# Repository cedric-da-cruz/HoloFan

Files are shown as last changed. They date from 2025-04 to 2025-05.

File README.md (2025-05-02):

# HoloFan
Conception of an holographic fan

- Datasheet : Contain the datasheets of the different components (if available)
- Deliverable : Contain document such as prestentation (pptx) ,report (pdf), and the Capella
- Electrical circuit : Contain the global powering circuit & the .json files (EasyEDA) of the PCB
- Manefacture : Contain the CREO files of the wooden box and PLA PCB case
- Software : Contain the different programs created and used
- Weekly Reports : Contain the weekly report to our tutor

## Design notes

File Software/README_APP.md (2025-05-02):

- In the file Fan_app.zip, you will find the files for the application of the fan. This is the software used to get an image send it to the fan.
- In the file Test_fan_app.zip, you will find the function used to test the integrity of the data by creating an image from the data in the byte array.

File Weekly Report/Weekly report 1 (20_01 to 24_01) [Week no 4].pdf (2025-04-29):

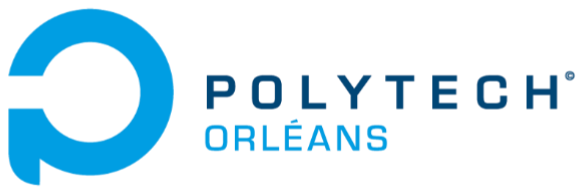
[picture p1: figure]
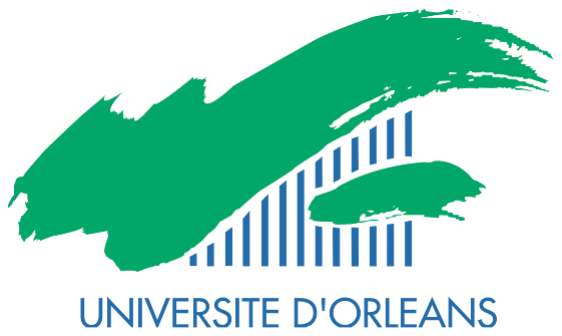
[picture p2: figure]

# Weekly Report

## Week 4 : 20/01/2025 – 24/01/2025

Eloïse MESTRE

Project Tutor

Mustafa TOPBAS

4A GPSE

Axel LEROY

4A GPSE

Cédric DA CRUZ

4A GPSE

Abigaïl BROCHARD

4A GPSE

Mustafa TOPBAS - Axel LEROY - Cédric DA CRUZ - Abigaïl BROCHARD - 4A GPSE
Eloïse MESTRE – Project Tutor | 1

1-Mustafa

Number of hours spent on the project this week: 10 hours

Activity:

Tuesday [21/01/2025]: I participated in amperage measurements on the

prototype. We unsoldered so we could measure the current in series with

a multimeter. With Cédric and Axel, we concluded that a minimum of 4.7V

was needed for around 300mA.

Wednesday [22/01/2025]: Given that the others were either absent or

presenting the specialty to younger students. I took the initiative to start

the electrical diagram including the LEDs, communication protocol and

microcontroller. After presenting this to the group and adjusting it

together, we distributed the tasks for the second semester. After that, I

wanted to start making a more serious electrical diagram on professional

software. The software we used in class did not include "footprint" of the

LEDs. This is important for the rooting process that we will encounter in the

future. So, I installed professional software. I started a diagram on it.

For the distribution of tasks, we decided that I was going to continue the

electrical diagram, make the PCB and work on the amperage and power

supply. Cédric will be with me for these games during this semester.

Thursday [23/01/2025]: With Axel and Ms. Debrus, we started the business

plan for our project. To do this, we filled out a BMC (Business Model Canva).

This table will be useful because it gives an overall vision of the business

plan, which we can return to in detail.

Friday [24/01/2025]: We reviewed what was wrong in our CDD (Capability

development document) with you, our tutor.

2-Axel

Number of hours spent on the project this week: 8 hours

Activities: I had 5 activities this week.

First activity: 1h

My first activity was to measure the inductive output current and

voltage needed to power the Arduino and the HC-06 (Bluetooth module)

with Mustafa and Cedric. We concluded that we needed a minimum of 4.7V

with a current of 300mA.

Second activity: 2h

My second activity was to continue the coding of the application. I

mostly worked on the way to get pixel data from an image. So, I worked in the same framework as the prototype’s app in C# (because I can reuse C#

functions in the .NET MAUI framework). I found the function lockbit that

returns an array of RGB data from a pixel of a Bitmap type image.

Third activity: 2h

My third activity was to help Cedric to make the motor work. We tried

several codes and tried to use several Arduino pins to control the motor,

but we didn’t manage to start the motor at all. We suspect the issue to be

with the ESC (Electonic Speed Controler) that is between the Arduino and

the motor, which is supposed power the motor. As there is very little data

about how to use this ESC, it is probable that we didn’t use it correctly.

Fourth activity: 1h

My fourth activity was to start the business plan of the project with

Mustafa and Ms. Debrus. We worked on how to make an appropriate

Business Model Canva for our project. For example, we determined who

would use our product, what services we could offer, or even how much

we could sell one of our products for.

Fifth activity: 2h

My fifth activity was to review the CDD (Capability Development

Document) with our tutor (you), Mustafa and Cedric.

3-Cédric
Number of hours spent on the project this week: 6 hours (+2 on Friday)

Activity:

Firstly, Axel, Mustafa, and me, tested the prototype to check the working

current and tension input. We concluded that we needed a minimum of

4.7V with a current of 300mA on the input coil for the prototype to be

powered properly. More extensive test will be needed on the final version

which will incorporate the chosen LEDs.

Secondly, I started working on the brushless motor and the ESC

(electronic speed controller). I encountered great problems as I couldn’t

make them work. The problem seems to originate from the ESC, as it

seems to need a specific starting protocol which wasn’t indicated on the

specifications of the product.

4-Abigail

Number of hours spent on the project this week:

Activity:

I was absent Tuesday and Wednesday morning, so I was only able to be

there Wednesday afternoon. I ordered the LEDs from Mr. LADROUZ. After

we have divided the tasks, I will take care of the design of the base to

print it with a 3D printer.

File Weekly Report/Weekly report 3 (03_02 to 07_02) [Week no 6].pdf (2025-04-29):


# Weekly Report

## Week 6: 03/02/2025 – 07/02/2025

Eloïse MESTRE

Project Tutor

Mustafa TOPBAS

4A GPSE

Axel LEROY

4A GPSE

Cédric DA CRUZ

4A GPSE

Abigaïl BROCHARD

4A GPSE

Mustafa TOPBAS - Axel LEROY - Cédric DA CRUZ - Abigaïl BROCHARD - 4A GPSE
Eloïse MESTRE – Project Tutor | 1

1-Mustafa

Number of hours spent on the project this week: 6.5 hours

Activity:

Monday [03/02/2025]: 3.5 hours

This morning, I used the diagram on paper that I had made for the system

power supply. I determined that it was necessary to receive 5V, 4A therefore

20W in total to power the blade. The induction component I had could only send

5V and 1A so it's not good enough. I tried to unsolder its rectifier part to measure

and make a rectifier myself later, but the transmitter burned, I don't know why.

I either must find a new component or take this one back to repair it by modify-

ing.

Wednesday [05/02/2025]: 3 hours

I started by looking for components to replace our burnt out induction

coils. I found a similar component that sends 100W, 24 to 32V and up to 4A.

Which corresponds to what I need to power the blade. I also looked for a

converter to be able to use the sector to power the system. I found a 220V to

24V converter. After that, I brainstormed with Axel to help with the code.

2-Axel

Number of hours spent on the project this week: 6 hours

Activities: I had 3 activities this week.

First activity: 2h30

My first activity was to keep working on the way to get RGB data from

the image. This time, using a “for” loop and adapting a bit the previous

program to get the lengths right, I managed to get the data from the whole

image, line by line. To lose as little time as possible, I didn’t try to display it

as I know the data stored in the byte array is right.

Second activity: 1h

My second activity was to help Mustafa with the measure of the

maximum power transmittable by the inductive coils. In doing so, the

inverter heated and burnt out. We don’t really know why as we used it with

a voltage of 12V and a current of 1A, which we had already used before and

worked well. These values being in the range written in the datasheet of

the component, we think one of the individual components had a fault.

Third activity: 2h30

My third activity was to work on the cropper and zoom part of the

app. Still in C# Winform, I managed to zoom in and out of an image with a

trackbar. Currently I am trying to work on a way to adapt the amount of

zoom possible to the original size of the image.

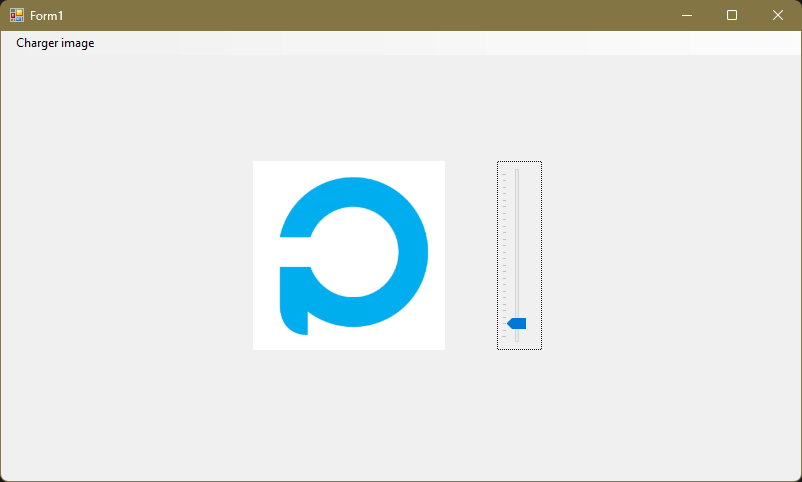
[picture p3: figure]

Screenshot of the app with the trackbar

3-Cédric
Number of hours spent on the project this week: 5 hours

Activity:

I mainly did test on the motor to check its power consumption

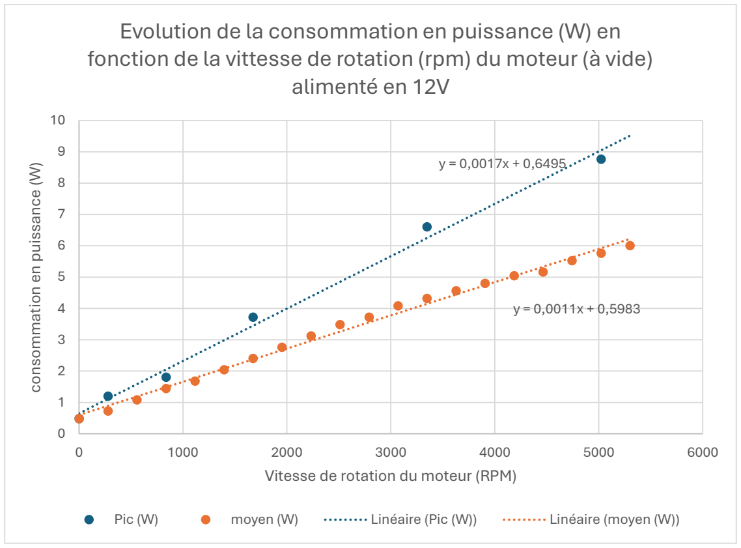
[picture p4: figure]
consommation en puissance (W); Vitesse de rotation du moteur (RPM); alimenté en 12V; Pic (W); moyen (W); Linéaire (Pic (W)); Linéaire (moyen (W))

For speed range (900-1300 RPM) we would have a maximum

consumption of 4W (12V 330mA).

I also tried repairing the induction coils but to no avails

### Evolution de la consommation en puissance (W) en fonction de la vittesse de rotation (rpm) du moteur (à vide)

4-Abigail

Number of hours spent on the project this week: 1.5h

Activity:

I was ill all week (and was off work for three days) and the doctor ordered

me not to work in order to get better. As soon as I felt better, I wanted to get

back to the project, because I know I'm behind schedule. I'm going to have a lot

of work to do next week, as my colleagues are making better progress.

Back to the facts:

I did an initial CAD test on Onshape

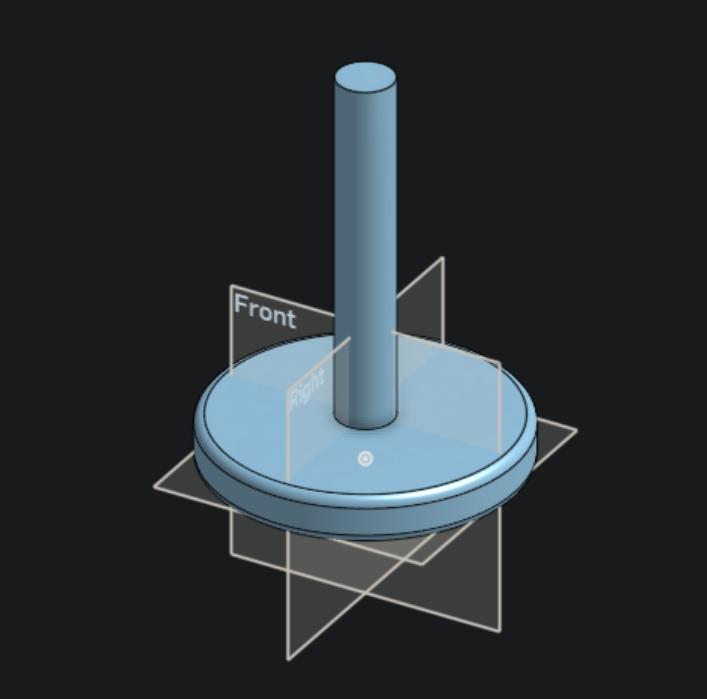
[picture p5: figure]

For the moment, there aren't any real measurements, but I wanted to fa-

miliarize myself with the software so that I could see for myself what we could

do with the boys and then send them into production.

I then started drawing the electrical diagram for my LEDs on EASYEDA to

check the connections to the datasheets and microcontrollers. It's not at all well

optimized yet, and on Monday I'll be drawing it on a sheet of paper to see how

to place everything properly.

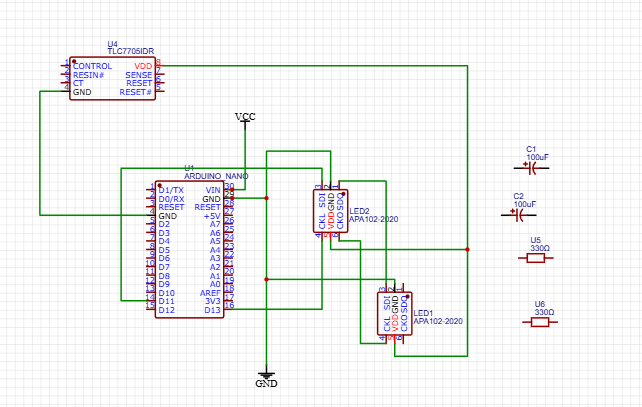
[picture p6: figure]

I know I'll have to add pull-up resistors and stabilizing capacitors to com-

pensate for voltage drops. But for the moment I've really technically linked the

various inputs and outputs and two LEDs together according to the SPI commu-

nication protocol:

DATA (DI) → MOSI (D11 on Arduino)

CLOCK (CI) → SCK (D13 on Arduino)

DATA OUT (DO) and CLOCK OUT (CO) go to next LED

VCC and GND in parallel on all LEDs

5V Power Supply → VCC of LEDs

GND Power Supply → GND of LEDs and Arduino

The connections will be in series for communication, and in shunt for

power supply.

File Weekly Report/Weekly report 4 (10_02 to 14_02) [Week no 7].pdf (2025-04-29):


# Weekly Report

## Week 7: 10/02/2025 – 14/02/2025

Eloïse MESTRE

Project Tutor

Mustafa TOPBAS

4A GPSE

Axel LEROY

4A GPSE

Cédric DA CRUZ

4A GPSE

Abigaïl BROCHARD

4A GPSE

Mustafa TOPBAS - Axel LEROY - Cédric DA CRUZ - Abigaïl BROCHARD - 4A GPSE
Eloïse MESTRE – Project Tutor | 1

1-Mustafa

Number of hours spent on the project this week: 6.5 hours

Activity:

Monday [10/02/2025]: 3 hours

Today, I started by learning about buck converters after a discussion with

Loann. After that, I looked at the LED footprint that Aby had found, we deter-

mined that it was not good. I then took a clean look at my power supply diagram

in Word. I now have to find a good buck converter and other components.

Thursday [13/02/2025]: 3.5 hours

Today I found the buck converter I needed as well as the 24V-12V con-

verter. After a discussion with Mr. Ladrouz, who explained to us that the orders

were going to be complicated and taking into account the fact that if we wanted

to manufacture these components ourselves, we would run out of time, we de-

cided to place the orders ourselves by dividing the sum by 4. The orders were

placed on Ali Express for budget reasons. These are the 4 components that I

chose. After that, I took the electrical diagram that Abigail made for the blade, I

checked it and I added the power supply part that I take care of. I plan to screw

the buck converter onto the PCB, I chose a component that provides holes for

this.

2-Axel

Number of hours spent on the project this week: 6 hours

Activities: I had 4 activities this week.

First activity: 2h

My first activity was to adapt the amount of zoom possible (and initial

zoom) according to the original size of the image. To do so, I used the zoom

function I had already made right after uploading the image on the

application. I also adapted the minimum zoom so that the image will fit to

the size even if it is originally smaller. Finally, I created factors that depend

on the size of the image to adapt the maximum zoom.

Second activity: 30 min

My second activity was to discuss with Cedric about the algorithm we

could use to transform the array of byte from x and y coordinates to r and

θ one. Indeed, to use the array in the Arduino, it would be easier to get the

RGB data using r and θ.

Third activity: 2h

My third activity was to try to move the image inside the picturebox

once it was zoomed in. I tried several ways, but I didn’t manage to make it

work. I intend to go back to work on this part, but as it is less important than some other parts of the app, I didn’t want to spend too much time

trying to make it work.

Fourth activity: 1h30

My fourth activity was to put all the individual working parts of the

app in one final app for the prototype. I will update frequently this app with

the new parts I manage to make work.

3-Cédric
Number of hours spent on the project this week: 6.5 hours

Activity:

I made some research for Axel on an algorithm that would transform an

image from cartesian coordinate to polar coordinate. I found some pre

existing code that could help and transfered it to Axel. I also worked with

Mustafa on plotting the electrical circuit.

4-Abigail

Number of hours spent on the project this week: 4h

Activity: Led diagram 3h

This week I reviewed the entire electrical diagram of the LED

I changed the footprint to exactly match the shape on the datasheet and

changed the connection placements as well.

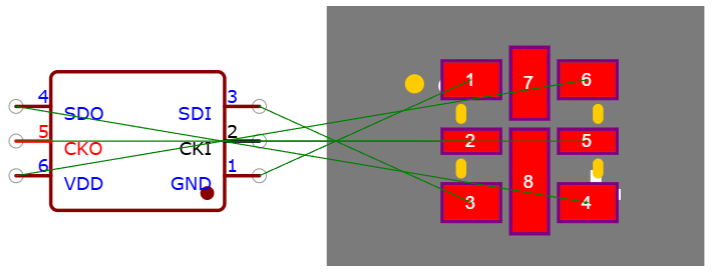
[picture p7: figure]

Then afterwards I had to try to place everything exactly as in the future fan,

remake the correct connections and do that 149 times.

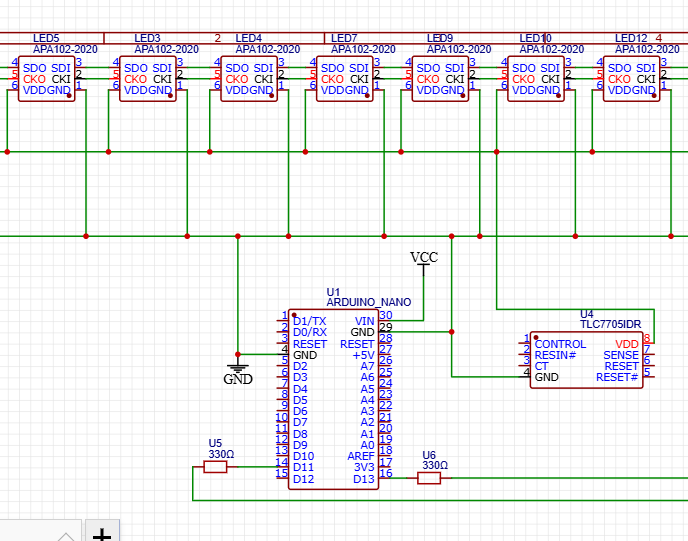
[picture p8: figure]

Activity: Business plan : 1h30

I took all the notes on the business plan that we had in relation to the

business canvas made earlier in the month to put everything in order. The

objective was to be able to prepare for the back-to-school oral exam.

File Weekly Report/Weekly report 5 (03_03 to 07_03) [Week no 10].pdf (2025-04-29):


# Weekly Report

## Week 10: 03/03/2025 – 07/03/2025

Eloïse MESTRE

Project Tutor

Mustafa TOPBAS

4A GPSE

Axel LEROY

4A GPSE

Cédric DA CRUZ

4A GPSE

Abigaïl BROCHARD

4A GPSE

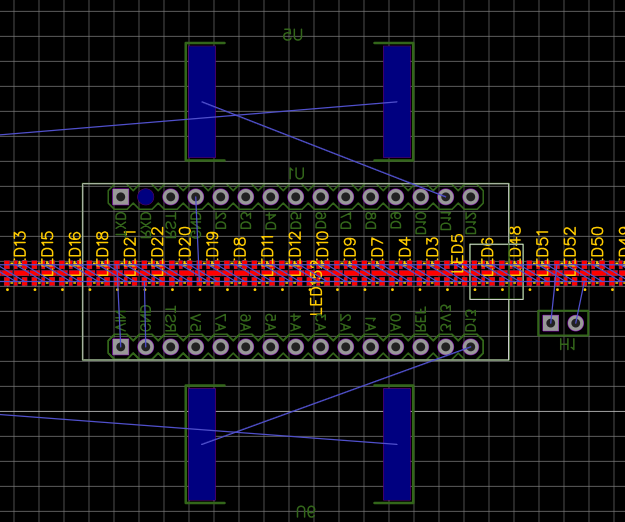
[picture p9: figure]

Mustafa TOPBAS - Axel LEROY - Cédric DA CRUZ - Abigaïl BROCHARD - 4A GPSE
Eloïse MESTRE – Project Tutor | 1

1-Mustafa

Number of hours spent on the project this week: 3.5 hours

Activity:

Monday [03/03/2025]: 3.5 hours

Today I started the PCB. I aligned the 150 LEDs which took me a lot of time.

I now must make the connections considering the width of the tracks to support

4A.

2-Axel

Number of hours spent on the project this week: 3.5 hours

Activities: I had 1 activity this week.

First activity: 3h30

My activity was to try to make work the translation function. As it is

not possible (or I haven’t found the way yet) to make it work with the

picture box, I tried to completely change the way I display the image. I tried

displaying it in several ways: inside a button, inside a rectangle entity, …

But I haven’t managed to make the translation work with the previous

functions.

3-Cédric
Number of hours spent on the project this week: 3.5 hours

Activity:

I did test on the replacement component we received. Since they aren’t

finished i’ll finish them and insert the result and graph on the next weekly

report

4-Abigail

Number of hours spent on the project this week: 3

Activity: Led and angular 3h

For this week, I asked Kamel for an angular sensor and some LEDs that could

be the closest to the ones I wanted for the project, so I could start coding

on them until I could buy the right materials.

The references for the LEDs are SK6812.

SK6812s are easier to connect and use fewer wires, but their

synchronization is not as good, which can be a problem if your system is

running at high speed.

- APA102s are much better for smooth, accurate display, thanks to

their SPI protocol and high refresh rate.

I'll have to take that into account for the code so I don't have too much

work to change the led afterwards.

For the angular sensor, the reference is the DR5013.

The DRV5013 is not a precise angular position sensor, it only detects

whether a magnet is present or not. It won't give you a precise angle.

- The AS5600 is designed for angular measurement and is much

more precise.

It's going to be more complicated to code because it's really not as good

as my basic sensor and Kamel doesn't have anything better, so I'll have to

find a solution quickly.

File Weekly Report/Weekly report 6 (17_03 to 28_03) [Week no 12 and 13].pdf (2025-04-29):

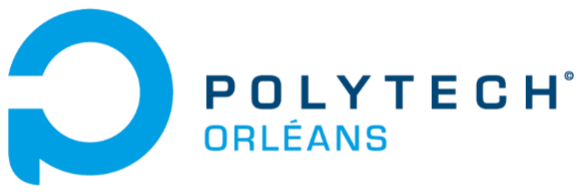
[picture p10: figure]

# Weekly Report

# Week 12-13: 17/03/2025 – 28/03/2025

## Eloïse MESTRE

## Project Tutor

## Mustafa TOPBAS

## 4A GPSE

## Axel LEROY

## 4A GPSE

## Cédric DA CRUZ

## 4A GPSE

## Abigaïl BROCHARD

## 4A GPSE

Mustafa TOPBAS - Axel LEROY - Cédric DA CRUZ - Abigaïl BROCHARD - 4A GPSE
Eloïse MESTRE – Project Tutor | 1

### 1-Mustafa

### Number of hours spent on the project this week: 2.5 + 4.25 + 4 + 2 =

### 12,75hours

### Activity:

Until March 26th at 12:30, I worked on the PCB that I had almost finished. All that remained

was to add the copper layers. But we received our LEDs which were deemed too small to be

soldered, which makes all my work on the PCB useless. So I will have to start again from the

electrical diagram. Also, the almost finished diagram had encountered problems that had

canceled all my connections, so I had to start again from the rooting. It was rather difficult to

believe that it was necessary to start all over again.

On the afternoon of March 26, I looked for the footprint, I found a similar one but I couldn't

import it. Mr. Ladrouz improvised a course for me on how to make a footprint but I still didn't

have all the keys to succeed.

I finally found a footprint that fit what I needed. I sent it to Abigail, who lined up the 60 LEDs

for me. We reduced the number of LEDs because the new ones are wider and we have PCB

size limitations.

On Friday, March 28, I took Abigail's aligned LEDs to make the electrical diagram of the project

once again. This time, I added the Hall effect sensor, the datasheet for which I had to read. I

also added the Bluetooth module. I did some research on the size of the tracks, for that I took

a book that we had to read as part of our courses. I ended up adding decoupling capacitors.

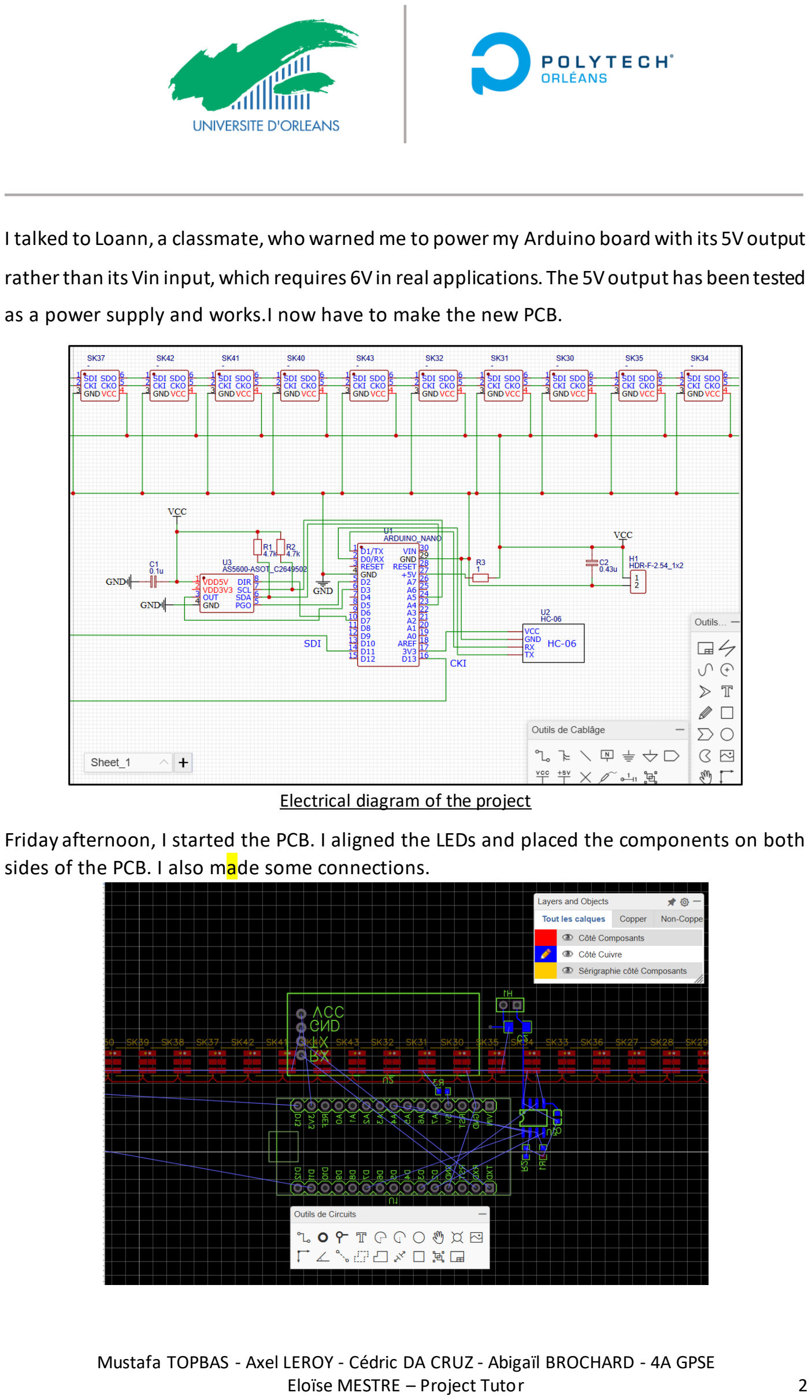
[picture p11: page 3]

I talked to Loann, a classmate, who warned me to power my Arduino board with its 5V output

rather than its Vin input, which requires 6V in real applications. The 5V output has been tested

as a power supply and works.I now have to make the new PCB.

Electrical diagram of the project

Friday afternoon, I started the PCB. I aligned the LEDs and placed the components on both sides of the PCB. I also made some connections.

### 2-Axel

### Number of hours spent on the project this week: 13h45

### Activity:

Last week, I used 3h45 to work on a way to move the image within the picturebox. I

had the idea to use a Graphicstype object which “tells” how manage the display of anything

graphic (images, drawings, etc). On this object I used the function FromImage(Image) to

specify which image the Graphics object applies to. Then, I used the function

DrawImage(Image, Point), which draws the image to the location specified by the point.

However,this function still isn’t enough to move the image within the picturebox because we

need to set the picturebox.Image (parameter to access the image of the picturebox) to this

new image. To do so I created a Bitmap object that copies the “new image” and then I set the

picturebox.Image to the Bitmap object. Beforehand, I also set the interpolation mode of the

Graphics object.

This week, I tried to crop the image once the user is satisfied with its size. To do so, I

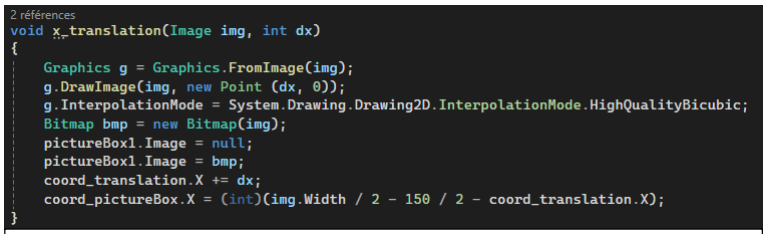
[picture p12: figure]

found | the | function

This function creates a copy of a section of a Bitmap. I could the same PixelFormat as the

original image, however I had to know what section I wanted to copy. To create a rectangle,

X_translation function, exists also for Y_translation we need a point to set the coordinates and a size. The size being set by the numbers of LEDs

on the fan. The biggest issue was the coordinates. Most of the 10 hours I spent on this part of

the project were related to these coordinates. It was easy to set a coordinates variable that

changes with the X and Y_translation functions, yet with the zoom function. So, I had to create

one point for X and Y_translation and one that always knows where the picturebox is within

the image (when the image is zoomed in, it theoretically is bigger than the picturebox, even if

we can only see the part inside the picturebox).

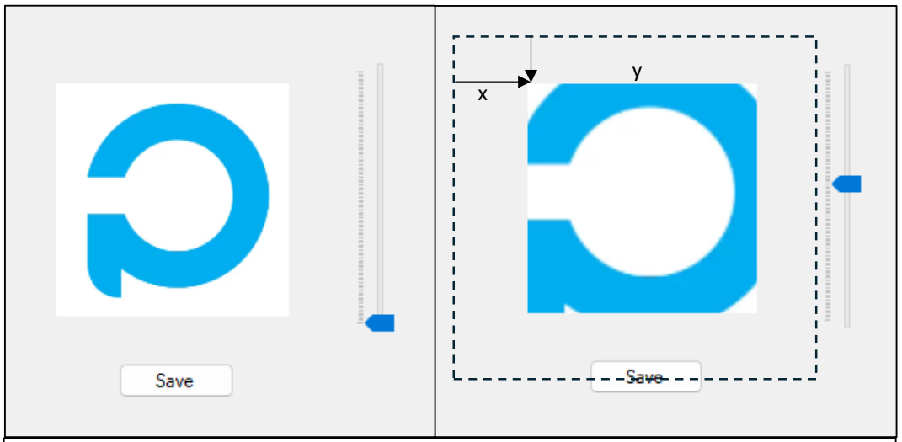
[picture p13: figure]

I also used these coordinates to manage the border limits of the image (not being able

to move outside of the image, nor to zoom out of the image when on one side).

Coordinates changing when zooming in/out

### 3-Cédric Number of hours spent on the project this week: 10

### Activity:

Last week I finished the different test on the component we received

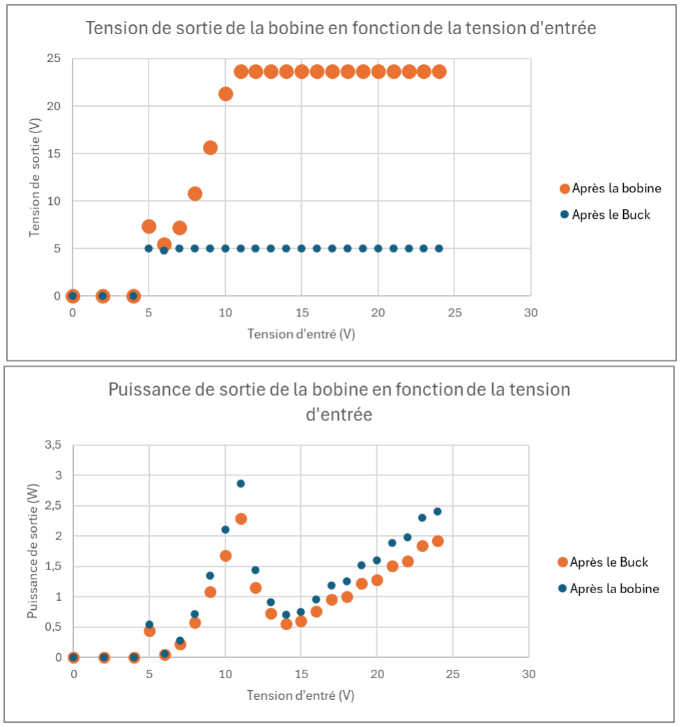
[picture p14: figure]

This week with Abigaïl we had a meeting with Ms NOVELLO, we discussed over the base on

which the motor will be fixed and who will contain the different electronic components. We

decided to go with 8mm thick composite wood and 10mm thick transparent plexiglass for

the materials. We have a meeting Friday next week to start the cutting and building process

### 4-Abigaïl

### Number of hours spent on the project this week: 2,5 (Wednesday March 26th

morning) + 2,5 (Wednesday March 26th afternoon) + 2 (Thursday March 27th evening) + 3,5

(Friday March 278h morning) -> 10,5

### Activity :

When we received our LEDs, we realized that they were really too small to solder ourselves.

It might have worked if we'd been able to subcontract, but it's not possible. So, I went to see

Kamel to try and find a solution, and we found a new reference of LEDs that would work.

We had to get away from the theory I had studied, which was that we needed small LEDs to

get the maximum number and exceptional synchronization.

The LED reference is SK9822. These are LEDs with the same communication protocol as the

old ones (APA-102), but their synchronization is slower than the others. They also have a more

unstable frequency starting at 4 MHz(compared with 20 MHzfor the others). These are details

that would count for a very professional rendering for a company, but we'll have to make do.

The LEDs are therefore larger. They're 5 mm in size, which means we'll have to use fewer of

them, and therefore get poorer quality. If we keep the 30 cm length for our pall, that gives us

60 LEDs.

So, I drew up the LED diagram with the new reference as quickly as possible, so that Mustafa

could start on the PCB on Friday morning. Fortunately, the SK9822s and APA-102s aren't that

far apart in terms of wiring, as this enabled me to go faster than if I'd had to start from scratch.

On Friday morning, Cédric and I went to the FABLAB to talk with Clarisse Novello about how

we're going to create the box that will hold our connectors and the Plexiglas protection. The

aim is to be able to fit the plexiglass and the wooden box together. Cédric can explain it better

than I can. Personally, I'll be modeling the plexiglass part in CREO with the following plans:

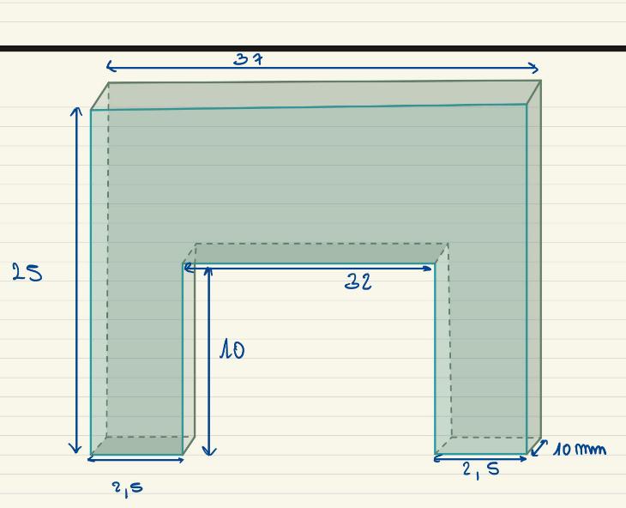
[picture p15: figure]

The drawing above is a side-by-side representation of the Plexiglasshape with measurements

(in cm overall and in mm where specified).

and below is the top view with measurements

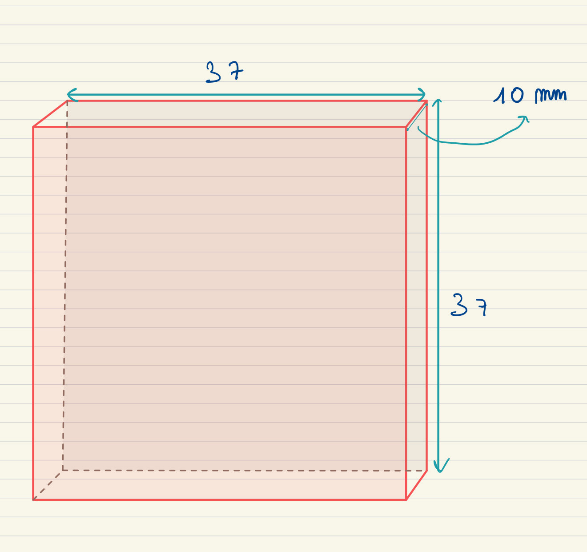
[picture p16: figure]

The aim is to finish all the modelling before next Friday, so that we can move on to laser cutting

during next week's slot, as we have made an appointment with Clarisse to get this done.

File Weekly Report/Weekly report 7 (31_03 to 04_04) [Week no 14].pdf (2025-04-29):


# Weekly Report

# Week 14: 31/03/2025 – 04/04/2025

## Eloïse MESTRE

## Project Tutor

## Mustafa TOPBAS

## 4A GPSE

## Axel LEROY

## 4A GPSE

## Cédric DA CRUZ

## 4A GPSE

## Abigaïl BROCHARD

## 4A GPSE

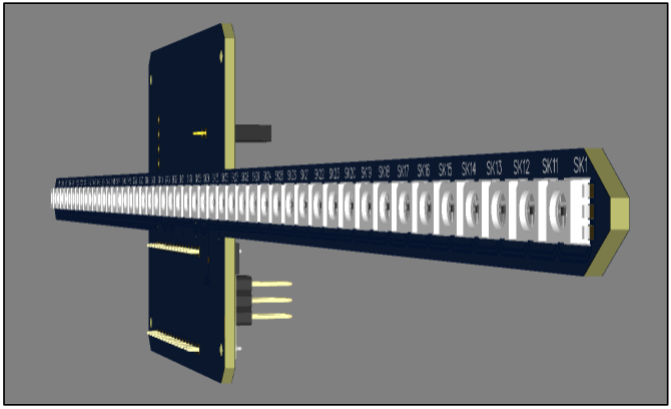
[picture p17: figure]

Mustafa TOPBAS - Axel LEROY - Cédric DA CRUZ - Abigaïl BROCHARD - 4A GPSE
Eloïse MESTRE – Project Tutor | 1

### 1-Mustafa

### Number of hours spent on the project this week: 4 hours

### Activity:

I finished all the PCB connections by correcting the last things that were wrong. I added a ground plane to finish. I then ordered the PCB from a subcontractor site. The PCB will arrive during the holidays, I couldn't do it at Polytech because of the technical limitations of the equipment. Once the PCB is received, we will have to solder the LEDs but it will be hard in terms of time.

3D view of the finished PCB

### 2-Axel

### Number of hours spent on the project this week: 3h

### Activity:

This week, I implemented the part of the code that gets the RGB data from an image

in the cropping part. To do so, I had to modify the way I previously got the RGB data and

changed the lockbit function. I previously used it on one line and looped it with a for loop,

changing the line each time. This way took too much time and sometimes bugged and kept

looping for too long. To avoid these issues, I used the lockbit function not on a line, but on a

rectangle. I now only had to put the size of the cropped image as the size of the rectangle and

use the function only once at the origin of the image. To check that the code worked properly,

I implemented the unlockbit function that can create an image from a byte array (of RGB data

for example). I finally tried to display an image in a second and bigger picturebox, using the

unlockbit function, to make sure that we could get all the data of the image and that the cropping part worked.

As we can see on the screenshot above, the only little issue we have is a black line at

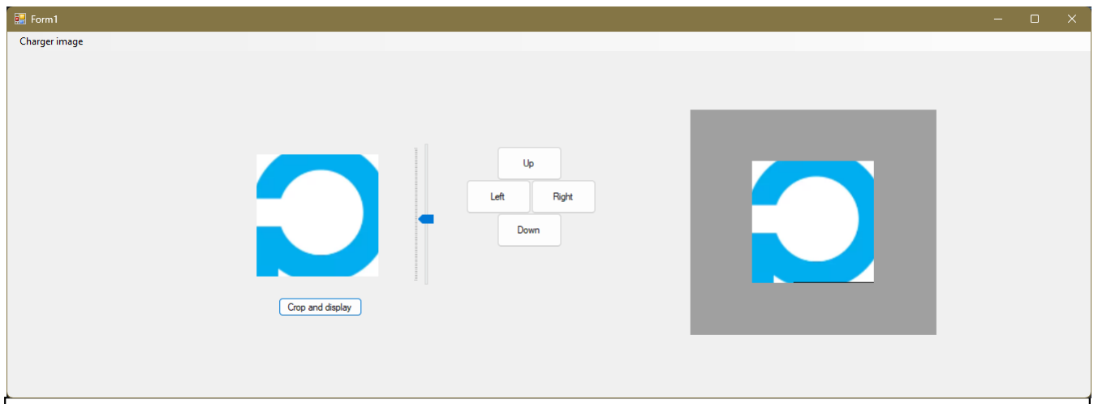
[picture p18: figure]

the bottom of the image. This issue doesn’t come from the change from line by line to

rectangle in the use of lockbit as the entire line would be black. I haven’t found yet why the

Test of the cropping part and display using lockbit and unlockbit bottom line is partly blackened, but I am still searching for a solution. Overall, most of the

image is displayed correctly so the next main activity I will have is to only display the image in

a circle.

### 3-Cédric Number of hours spent on the project this week: 4 hours

### Activity:

We (Me and Abigaïl) finished the plan for the base and had our meeting with Ms Novello.

We then started the cutting process (½ done). We’ll finish the cutting next week and start

building it up and fix the electronic components to it.

### 4-Abigaïl

### Number of hours spent on the project this week: 4h

### Activity :

The new LEDs and angular sensor arrived this week. We then spent the morning with Cédric

at the FABLAB to finish the plans for the box and start cutting with Mrs Novello. We're meeting

again on Wednesday to finish cutting and start fixing the elements.

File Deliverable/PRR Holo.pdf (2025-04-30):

# PRR

## Holographic fan

The 30th of april 2025

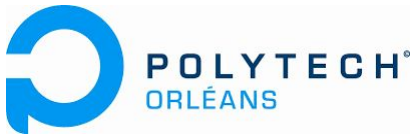
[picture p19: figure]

Mustafa TOPBAS, Axel LEROY, Cédric DA CRUZ, Abigaïl BROCHARD

## Introduction / quick presentation

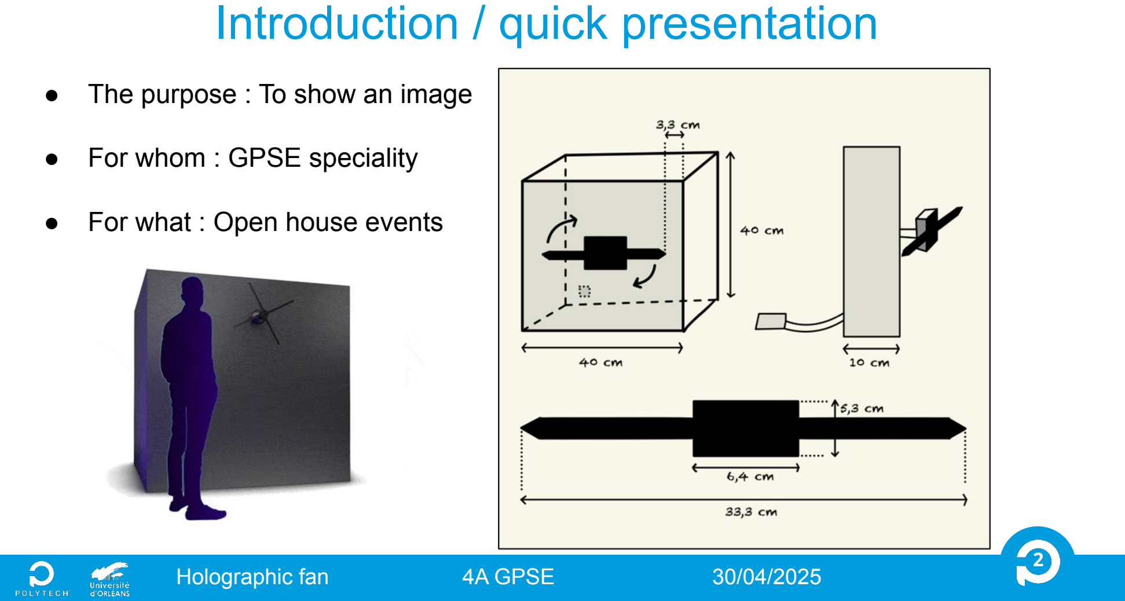
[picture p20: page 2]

2
Holographic fan | 4A GPSE | 30/04/2025
- The purpose : To show an image
- For whom : GPSE speciality
- For what : Open house events

3

## Table of contents

### I. Reminder : - Use case - Functional analysis

### II. Technical solutions

### III. Work distribution

### IV. Skills and learning

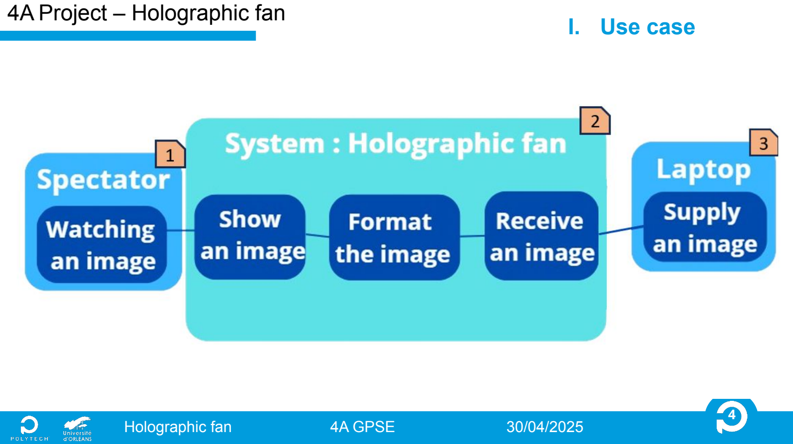
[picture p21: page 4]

4

4A Project – Holographic fan
I. Use case

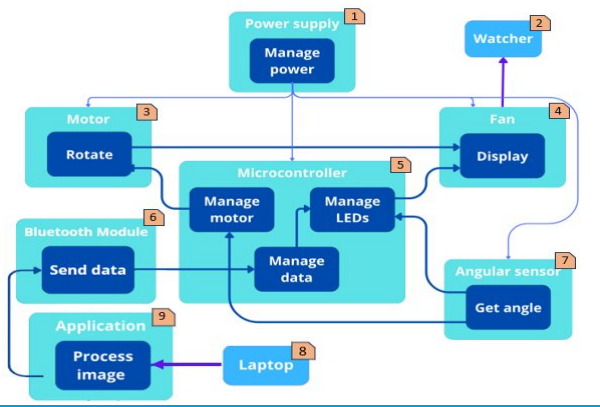
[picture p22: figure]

5

I. Functional analysis

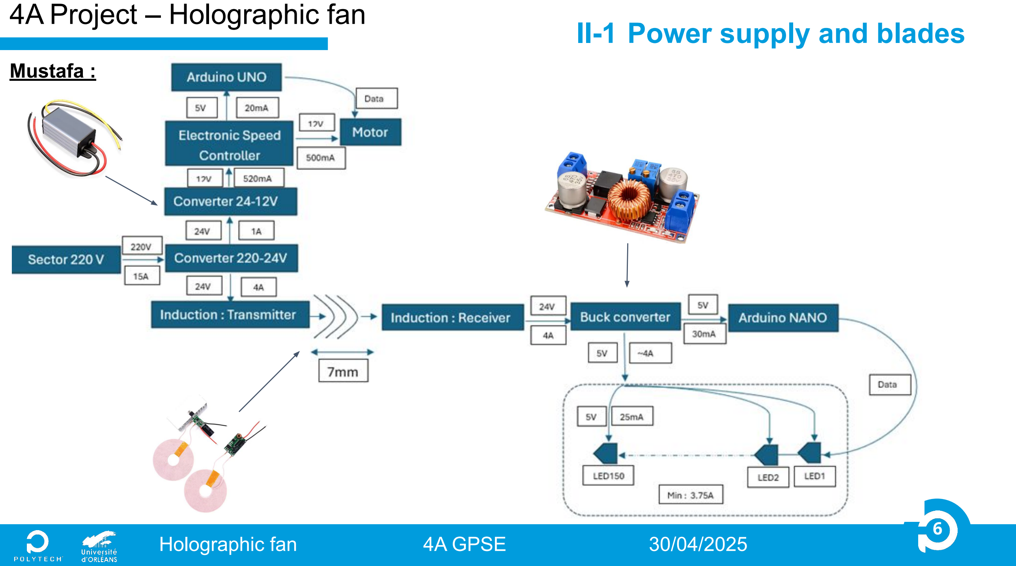
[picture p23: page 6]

6

II-1 Power supply and blades

Mustafa :

Mustafa :

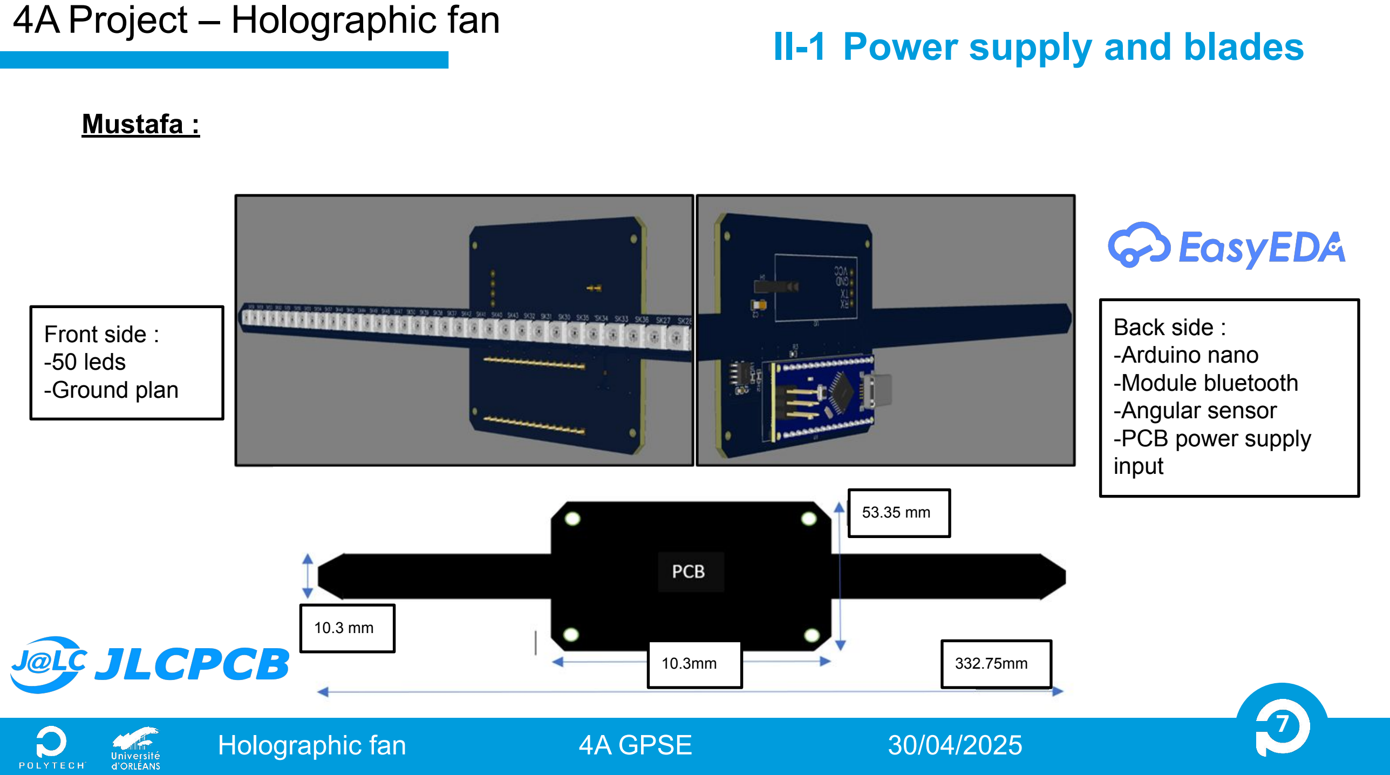
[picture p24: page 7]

7

II-1 Power supply and blades

Mustafa :

10.3 mm

53.35 mm

10.3mm | 332.75mm

Front side :
-50 leds
-Ground plan

Back side :
-Arduino nano
-Module bluetooth
-Angular sensor
-PCB power supply
input

8

II-2 LEDs and sensors


Abigaïl:


9

II-2 LEDs and sensors

Abigaïl:

10

II-2 LEDs and sensors

Abigaïl:


Cédric: Components; Brushless motor; - 930 RPM/V; - 30A maximum; - PWM communication; - Controlled by μ-processor; Electronic Speed Controller

11

II-3 Motor & motor management

12

II-3 Motor & motor management


Cédric: Test

13

II-3 Motor & motor management

Cédric: Make the motor spin at the requested speed

Library “Servo.h”

Initialisation process

Loop for speed increment (0 -> 11600 RPM)
- Width expansion of PWM
impulse(1000->2000)

Calibration Code

Library “Servo.h”

Initialisation process

Fix speed (PWM width 1063⇔ 700 RPM)

Spinning Code

Link to the Github :

https://github.com/cedric-da-cruz/HoloFan


14

II-3 Motor & motor management

Cédric: Test

15

II-4 App and data


16 mm

Axel:

HC-06
HC-06
Bluetooth version | Bluetooth 2.0
Frequency | 2,4 GHz
Max data transfer rate | 2,1 Mb/s
Communication protocol | UART
Power supply | 5V
Dimensions | 16X37mm


16

II-4 App and data

Axel:

Link to the Github :

https://github.com/cedric-da-cruz/HoloFan

17

II-5 Manufacturing

Cédric:


18

II-5 Manufacturing

Cédric:


III-1 Work distribution; Second semester

20

IV- Skills and learning : Mustafa

- Design an electronic board (schematic + PCB)
- Tests on the prototype (test the soldered board)
- Select the scientific instrumentation (general system power

supply)

- Plan a development project (organization, deliverables and

milestones)

- Manage a development project with a systems approach
- Write a datasheet

21

IV- Skills and learning : Cédric

- Assemble various analogue and digital components
- Implement existing code or libraries
- Selecting technological building blocks
- Study and write a datasheet
- CAO Software
- Manufacturing machines

22

IV- Skills and learning : Abigaïl

- Designing an electric diagram (EASYEDA)
- Assemble various analog and digital components
- Selecting technological building blocks
- Study and write a datasheet

23

IV- Skills and learning : Axel

- Assemble various analogue and digital components
- Implement existing code or libraries
- Develop code or libraries
- Design a Human Machine Interface
- Select interaction / communication modes
- Develop a processing strategy in a constrained context
- Write a progress report

24

# Demonstration video for LEDs

25

# Conclusions

Power and blade :

- The | second blade | manufactured (Everything is welded:

approximately 330 welds) and tested: non-functional

- The | power supply | is working, the PCB circuit is distributing the

power poorly.

26

# Conclusions

Motor & Motor management :

- It worked as it should
- ESC ceased to function yesterday

27

# Conclusions

LED and angular sensor:

- LEDs and angular sensor are soldered
- LEDs light up
- The angular sensor could not be tested because the PCB was not working.

28

# Conclusions

App and Bluetooth :

- The HC-06 is soldered and tested
- The application can get an image, resize it, move it, get the

RGB data and send data via Bluetooth

- The integrity of the RGB data has been tested in the code by

re-displaying the image from the RGB data

- The use of polar coordinates doesn’t work

29

# Conclusions

Manufacture :

- Lack of protection
- Slightly unstable when spinning

30

# Perspectives

Power and blade :

- Repeat tests thoroughly to determine the malfunction
- Create a 3rd PCB with the corrections made

31

# Perspectives

Motor & Motor management :

- Buy new ESC
- Protection against big variation of amps

32

# Perspectives

LED and angular sensor:

- Retest the LED with a new PCB
- Connect application, sensor, arduino and LED

33

# Perspectives

Application :

- Use polar coordinates
- Make it easier to use
- Create another one for other devices

34

Manufacture :

- 3rd Version of the PLA PCB case (narrower & circular -> lighter)
- Plexiglass shield (protection)
- 2nd fixation for the upper part of the wooden box (better stability)
- ON/OFF switch

# Perspectives


35

Annex:

First semester


36

Annex :


37

Annex: Risk analysis


38

Annex: Corporate Social Responsibility

Societal

Environmental | Economic


39

- Easy to reproduce
- Being able to make it accessible to everyone
- Make a user manual
- Kit project

Annex: Corporate Social Responsibility


40

- Representation tool for the specialty
- Attracting young people to technology

Annex: Corporate Social Responsibility


41

Main objectives :

- Selection of materials with the least environmental impact
- Optimization of product’s lifespan

To go further :

- Reduction in the quantity of materials
- Reduce the environmental impact of the use phase
- Optimization of the end of life of the system

Annex: Corporate Social Responsibility

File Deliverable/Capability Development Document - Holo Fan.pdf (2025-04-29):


# CDD


# Capability Development Document

## January 17, 2025

## Eloïse MESTRE

## Project Tutor

## Mustafa TOPBAS

## 4A GPSE

## Axel LEROY

## 4A GPSE

## Cédric DA CRUZ

## 4A GPSE

## Abigaïl BROCHARD

## 4A GPSE

Mustafa TOPBAS - Axel LEROY - Cédric DA CRUZ - Abigaïl BROCHARD - 4A GPSE Eloïse MESTRE – Project Tutor
January 17, 2025 | 1

Summary

Mustafa TOPBAS - Axel LEROY - Cédric DA CRUZ - Abigaïl BROCHARD - 4A GPSE

## Introduction

This 2nd year engineering cycle project proposed by the Engineering Physics and Embedded

Systems speciality for its students is called ‘Holographic Fan. It was assigned to the writers of this

document at the beginning of the school year and is spread over the year. It consists of concretising

the project during the first semester of the year. This first part includes 3 presentations during which

the students are assessed on their progress. By 17 January, students must have a usage scenario, a

functional diagram, preferably drawn up in Capella, and technical solutions. They must also be able to

demonstrate critical functions or high added value with a prototype. The second semester will be

devoted to manufacturing.

The final holographic propeller must be able to act on an image chosen by the user in order to

display it. This will be achieved by rotating a paddle at a constant speed, on which LEDs will be

distributed at regular intervals, flashing according to a programme also written by the project

members. The code must be easy for the user to install, so it will be an installable software/application.

The final object will be exhibited during the school's open days and should promote the ‘engineering

physics and embedded systems’ speciality.


Mustafa TOPBAS - Axel LEROY - Cédric DA CRUZ - Abigaïl BROCHARD - 4A GPSE

## 1- Functional synoptic diagram of the project

### 1-1 Use case


Mustafa TOPBAS - Axel LEROY - Cédric DA CRUZ - Abigaïl BROCHARD - 4A GPSE

### 1-2 Fast digram

The purpose of the fast diagram is to go through the major functions found by analyzing the

life cycle of the product in order to make a specification table.

The fast diagram of the project


Mustafa TOPBAS - Axel LEROY - Cédric DA CRUZ - Abigaïl BROCHARD - 4A GPSE

### 1-3 Specification table and conformity test planned

Specifications and conformity


Mustafa TOPBAS - Axel LEROY - Cédric DA CRUZ - Abigaïl BROCHARD - 4A GPSE

## 2- System architecture

The system architecture shows the main components used for the system, their behaviours

and their relationship to each other.

### 2-1 Global view of the system architecture

Global view of the system architecture on Capella


Mustafa TOPBAS - Axel LEROY - Cédric DA CRUZ - Abigaïl BROCHARD - 4A GPSE

### 2-2 Motor management and power supply

Motor management and power supply architecture on Capella


Mustafa TOPBAS - Axel LEROY - Cédric DA CRUZ - Abigaïl BROCHARD - 4A GPSE

### 2-3 Fan, Angular sensor and LED management

Angular sensor, LED management and fan architecture on Capella


Mustafa TOPBAS - Axel LEROY - Cédric DA CRUZ - Abigaïl BROCHARD - 4A GPSE

### 2-4 Application and image data

Image data and application architecture on Capella

## 3- Functional set

### 3-1 Application and image data management

The objectives of this functional package

To be able to display an image on the fan, the first thing needed is the image and its data. As

we want everyone to be able to use the fan, we need to create an application that allows users to

choose an image and to send it to the fan, which will then display it. However, the fan has a limited

resolution and not every image will fit. To make sure any image of any resolution or any format can be

displayed, the app needs to be able to open any format of image and to have the user crop an image

to the fan resolution. The application also needs to be able to connect to the fan wirelessly and to send

the data of the cropped image, while still being intuitive. Finally, the fan needs to associate each pixel

of the image to each of its LED and angular position.

Mustafa TOPBAS - Axel LEROY - Cédric DA CRUZ - Abigaïl BROCHARD - 4A GPSE

Choices

In this part of the project there were very little choices to make. The most important is the

choice of the framework in which the application will be coded. As the application is supposed to be

accessible to everyone, it needs to work on IOS, Android and Windows devices. To do that there are

two ways possible: create different applications in different frameworks for each type of device or

create one application in a cross-platform framework.

Whatever choice was made, we had to learn to use at least one framework that we didn’t know

before. To gain time, it was decided to use a cross-platform framework and learn only one framework.

The most interesting for us was the .NET MAUI framework, using C# for the backend and XAML for the

frontend. However, in case we don’t manage to learn it in time, we consider using the first choice as

backup for the frameworks we already know (such as C# WinForm for Windows devices).

Considering the choice of the wireless technology, we had the possibility to choose either

Bluetooth or Wi-Fi. In theory, both technologies are fast enough to upload the data from the app to

the fan. For simplicity reasons, it was decided to use Bluetooth. To do so, we decided to use a HC-06

Bluetooth receiver on the fan’s end.

Detailed technical description

The chosen framework is called .NET MAUI and uses C# and XAML to do the backend and

frontend of cross platform applications. The application we intend to program should first be able to

get a picture file from the user’s device and let the user crop it. The formats supported should be at

least .png, .jpg and .gif. If the resolution is too high (more pixels than the fan can display), the

application should reduce the resolution by using average RGB values of a certain group of pixels. If

the resolution is too low (the fan has more pixels than the image), several fan pixels will show the

same image pixel. The application should then allow the user to send the data to the fan.

The HC-06 Bluetooth receiver is a 16mm by 37mm module that works on Bluetooth 2.0

communication protocol between frequencies of 2,402 GHz and 2,480 GHz. It can only receive data

and transmit it via UART to the microcontroller. It can receive and transmit data up to a rate of 2,1

Mb/s. Its 4 pins are Vcc (power voltage, 5V), GND (Ground), TXD (transmitter data pin for UART

protocol), and RXD (receiver data pin for UART protocol).

Mustafa TOPBAS - Axel LEROY - Cédric DA CRUZ - Abigaïl BROCHARD - 4A GPSE

### 3-2 Engine and engine management

The objectives of this functional package

To make the fan spin fast enough to trick the eyes(approximately 10 rotation/s for a dual blade

fan). At high speed the eyes won’t be able to see the spinning blades of the fan. Thus, he will only be

able to see the light emitted by the LEDs, creating the illusions of a floating image or more commonly

named a hologram. While doing so, the blades must stay fixed to the fan to ensure security and

functionality. The blades must also be inaccessible while they’re spinning so that no one can hurt

themselves by getting too close.

To ensure that the illusions and the image are maintained the blades need to spin at a constant

speed so there is also a need for a controller/manager.

Choices

Motors were easily chosen as the way to make the blades spin, as they are specialised at

creating rotational forces. 3 types of motors could be used to make the blades spin:

- Stepper motor (DC): + constant speed, precise control / - low speed
- Continuous motors (DC): + cheap, high speed / - speed variation
- Brushless motors (DC): + high speed, constant speed, precise control / - difficult to control

The brushless motors were finally chosen as they were the most adapted one, having a

constant and high speed of rotation. An ESC (Electronic Speed Controller) being the easiest and most

used way of controlling a brushless motor, it was decided to use one.

Detailed technical description

A A2212/15T 930KV brushless motor was bought with its associated 30A ESC. It’s a tri-phased

motor which spins by alternatively changing the magnetic force of the motor’s coils. This model is a

cylinder, 22mm high and with a 12mm radius . It has 15 turns per magnetic poles and can generate a

speed of 930 RPM / Volt.

It’s speed, stability, controllability will be tested, as well as its torque to check its limits.

Mustafa TOPBAS - Axel LEROY - Cédric DA CRUZ - Abigaïl BROCHARD - 4A GPSE

### 3-3 LED management and angular sensor

The objectives of this functional package

The main objective of this functional package is to ensure synchronization between the LEDs

and the angular position of the rotating fan. By achieving precise timing and precise colour control of

the LEDs, the system aims to recreate a clear and stable image when the fan spins. This involves being

able to send the colour to the LED, the LEDs having good sensitivity and coordinating the activation of

the LEDs based on real-time position feedback from the angle sensor. The microcontroller-LED

connection must be managed so that communication is as fluid as possible. Each LED needs to know

what colour it should be as quickly as possible.

Choices

In this part there is the choice of the angular sensor and, of course, the LEDs

After careful consideration, the APA102-2020 LEDs were selected for their high refresh rate,

individual control and communication protocol (SPI). These features make them ideal for maintaining

synchronization with the angular position of the fan, which is crucial for displaying a stable image.

However, other LEDs, such as the APA104-1010, were also evaluated for their smaller size, but were

not chosen due to their single-wire communication, which could complicate high-speed timing

accuracy as well as their lack of stability at high speed.

The second key decision focused on the angular position sensor. Accurate and reliable position

feedback is essential to synchronize the LEDs with the rotation of the blades. The AS5600 sensor was

chosen for its compact size, high precision and I2C communication protocol. Other sensors, such as

optical rotary encoders or rotary resolvers, have been evaluated but rejected due to complexity, cost,

or less favourable integration with the rest of the system.

The last key decision concerns the microcontroller used to control the LEDs and the sensor.

The two options were the Arduino or the STM32. The Arduino is simpler to code with already existing

libraries for the chosen LEDs. Certainly, less efficient than the STM32, coding in Arduino will save

considerable time.

Mustafa TOPBAS - Axel LEROY - Cédric DA CRUZ - Abigaïl BROCHARD - 4A GPSE

Detailed technical description

APA102-2020 LEDs are RGB LEDs measuring 2mm by 2mm. The objective is to glue them one

by one to make 150 (the total length being 300 mm for the blades). Each LED requires 32 bits of data:

8 bits for brightness and 24 bits for RGB colour control, with 8 bits per colour channel. Operating at a

voltage of 5 V DC, each LED consume approximately 60 mA at maximum brightness (for pure white).

For a configuration of 150 LEDs, the total consumption is around 45 W at full power. Their high refresh

rate of up to 20 kHz, theoretically without scintillation.

The AS5600 magnetic rotary position sensor provides precise 360° angular measurements.

With a resolution of 12 bits (4096 positions for 360°), it can more easily detect the position of the blade

to send the information to the LED. The AS5600 operates over a voltage range of 3.3V to 5V and

consumes only 6mA. The sensor communicates with the microcontroller via I2C. This can work

simultaneously with the LEDs which are in SPI.


Mustafa TOPBAS - Axel LEROY - Cédric DA CRUZ - Abigaïl BROCHARD - 4A GPSE

### 3-4 Power supply and the fan

The objectives of this functional package

The mechanical connection between the motor and the fan must be determined in order to

ensure stable power transmission. The best way to power the rotating part should be identified to

avoid any risk of damage to the cables. Finally, it is necessary to design an optimal armature, defining

the best way to arrange the LEDs on the propeller to produce a holographic display.

Choices

Solutions had to be sought and found for this part. The first step was to identify the best way

to feed the system. Then find out how to make the propeller blade. We also had to find a way to power

a part that was running, so it wasn't possible by cable. Tables with selection criteria according to their

importance have made it possible to identify the best solutions that will be kept for manufacturing.

Criteria table for the system power

Criteria table for the blade

Criteria table for the powering of the blade

Vin; Vout (average)

Detailed technical description

At the end of this, the choice to use rechargeable batteries, to make the blade in the form of

a PCB as well as to power the rotating part by induction was kept. Components have been ordered
for initial induction testing. We had to find the transmitted voltage according to the distance.

Fixed distance = 0 mm | Vin V | Vout (average) V

1,5 | 0
2,5 | 0
3,1 | 0
3,2 | 0
3,3 | 0

Distorted signal | 3,4 | 2,03
Distorted signal | 3,6 | 3,07
Distorted signal | 3,8 | 3,85
Near-continuous signal | 4 | 4,4
Continuous signal | 4,5 | 4,88
Continuous signal | 5 | 4,88
Continuous signal | 5,5 | 4,88
Continuous signal | 10 | 4,88

Graphic of the evolution of the output voltage according to
the input with a fixed distance

Fixed voltage = 12 V | Distance mm | Vout

Table of the evolution of the output
voltage according to the input with a fixed
distance

0 | 4,88
2,5 | 4,88
5 | 4,88
7,5 | 4,88
10 | 4,88
12,5 | 4,88
15 | 4,88
17,5 | 4,88
20 | 4,7
22,5 | 0
25 | 0
27,5 | 0
30 | 0

Fixed voltage = 5 V | Distance mm | Vout

2,5 | 4,8
5 | 3,8
7,5 | 2,1
10 | 0
15 | 0
20 | 0

Table of the evolution of the output voltage
according to the distance with a fixed voltage

according to the distance with a fixed voltage (12V)

Mustafa TOPBAS - Axel LEROY - Cédric DA CRUZ - Abigaïl BROCHARD - 4A GPSE

Mustafa TOPBAS - Axel LEROY - Cédric DA CRUZ - Abigaïl BROCHARD - 4A GPSE

## 4- Risk analysis

### Catastrophic

| (5) | Considerable (4) | Medium (3) | Low (2) | Negligible (1)
Certain (5) | 25 | 20 | 15 | 10 | 5
Probable (4) | 20 | 16 | 12 | 8 | 4
Occasional (3) | 15 | 12 | 9 | 6 | 3
Rare (2) | 10 | 8 | 6 | 4 | 2
Unlikely (1) | 5 | 4 | 3 | 2 | 1
Identified Risk | Probability of occurring | Impact on the project | Risk score | Proposed solution to reduce the risk
HOLO3DLED company that does not send the promised package | Probable | Negligible | 4 | Not be dependent on the study of a func-tional fan
Injury caused by the fan while spinning | Unlikely | Catastrophic | 5 | Make the fan untouchable during its rota-tion
Application/Site unable to handle traffic | Rare | Catastrophic | 10 | Make the app/site independent of traffic
Too high ambient light (indoors) | Rare | Medium | 6 | Ensure a brightness equivalent to the in-door lighting standard
Fan that flies away | Rare | Catastrophic | 10 | Ensure sufficient weight of the base
Blades that detach | Rare | Catastrophic | 10 | Keep the blades fixed and prevent un-screwing via vibration
Fan that pitches | Occasional | Considerable | 12 | Light fan/Stable Base (Big Block?) and Stable Axis of Rotation
System Short Circuit | Occasional | Considerable | 12 | Spare part and test point (circuit breaker?)
No compatibility with any system (IOS, Android, Windows, etc) | Probable | Medium | 12 | Used a Cross-System Programming Tool
Image processing problem | Rare | Considerable | 8 | Pre-Display Confirmation Step/ Simple Image
Fan connection problem | Unlikely | Catastrophic | 5 | Keeping the distance reduced as possible and without obstacle

Mustafa TOPBAS - Axel LEROY - Cédric DA CRUZ - Abigaïl BROCHARD - 4A GPSE

## Conclusion

In summary, this project on the development of a holographic fan combines technical

innovation and practical engineering to achieve a visual effect. It demonstrates the application of core

concepts in motor control, LED synchronization, wireless communication, and image processing, all

while adhering to safety and usability standards. Moving forward, careful implementation of the

proposed solutions and continuous testing will ensure that the final product is both functional and

impressive, serving as a compelling showcase for the Engineering Physics and Embedded Systems

speciality.

Mustafa TOPBAS - Axel LEROY - Cédric DA CRUZ - Abigaïl BROCHARD - 4A GPSE

## Table of Appendices

## A - All useful sources

## B – Software

## C - CSR approach

## D - Distribution of work

## E - Self-assessment of skills acquired/strengthened and CV

Mustafa TOPBAS - Axel LEROY - Cédric DA CRUZ - Abigaïl BROCHARD - 4A GPSE

## A - All useful sources

Lien Web:

Engine & Engine management

https://arduino.blaisepascal.fr/controler-un-moteur-brushless/

https://youtu.be/xiRyQOrpP0E?

https://youtu.be/Be50YbIuTuc?

https://stsolutions.ch/principaux-types-moteurs-electriques/

https://eric-walschaerts.canoprof.fr/eleve/LES_MOTEURS/LES_MOTEURS_ELECTRIQUES/

https://conceptek.net/fr/techniques-de-base/conception/machines-et-composants/quels-sont-les-

diff%C3%A9rents-types-de-moteurs-%C3%A9lectriques (https://conceptek.net/fr/techniques-de-base/conception/machines-et-composants/quels-sont-les-diff%C3%A9rents-types-de-moteurs-%C3%A9lectriques)

https://www.electricity-magnetism.org/fr/5-types-de-moteurs-electriques-les-plus-communs/

https://interactive.3demotion.net/blog-

helice/#:~:text=Son%20principe%20est%20simple,ne%20voit%20pas%20l'h%C3%A9lice (https://interactive.3demotion.net/blog-helice/)

https://matel.com/wp-content/uploads/fiches_techniques/MLHHx

https://www.plv-hologramme.fr/helipix

LED management & angular sensor

https://files.seeedstudio.com/wiki/Grove-12-bit-Magnetic-Rotary-Position-Sensor-

AS5600/res/Magnetic%20Rotary%20Position%20Sensor%20AS5600%20Datasheet.pdf (https://files.seeedstudio.com/wiki/Grove-12-bit-Magnetic-Rotary-Position-Sensor-AS5600/res/Magnetic%20Rotary%20Position%20Sensor%20AS5600%20Datasheet.pdf)

https://www.mouser.com/datasheet/2/737/APA102_2020_SMD_LED-

2487271.pdf?srsltid=AfmBOoohDNiSU36U6w5PKeeTQEbeQk5pGfmWQD-KM6JJ3rQY8_dBXoU6 (https://www.mouser.com/datasheet/2/737/APA102_2020_SMD_LED-2487271.pdf)

Mustafa TOPBAS - Axel LEROY - Cédric DA CRUZ - Abigaïl BROCHARD - 4A GPSE

Application and data

https://www.youtube.com/watch?v=Hh279ES_FNQ&list=PLdo4fOcmZ0oUBAdL2NwBpDs32zwGqb9DY

ImageCropper.Maui 1.2.3 on NuGet - Libraries.io - security & maintenance data for open source software (https://libraries.io/nuget/ImageCropper.Maui)

Votre Arduino communique avec le module HC-06 • AranaCorp (https://www.aranacorp.com/fr/arduino-et-le-module-bluetooth-hc-06/)

Getting RGB array from image in C# - Stack Overflow (https://stackoverflow.com/questions/4747428/getting-rgb-array-from-image-in-c-sharp)

Implementation of the Bluetooth Connectivity Using .NET MAUI (https://www.c-sharpcorner.com/article/implementation-of-the-bluetooth-connectivity-using-net-maui/)

https://youtu.be/mMByPw8_TMw?list=PL-oGQIjmlO23SJ3Pim42ImNGW4ci2xcoX

Power supply and fan

https://www.gotronic.fr/art-coupleur-10-piles-lr6-em10-5724.htm

https://www.gotronic.fr/art-connecteur-eco-9v-en-i-5696.htm

https://www.gotronic.fr/art-module-de-charge-par-induction-wcm5-1-31351.htm

Mustafa TOPBAS - Axel LEROY - Cédric DA CRUZ - Abigaïl BROCHARD - 4A GPSE

## B – Software

DSEE Labs Software for PC & Phone: Link (https://www.dseelab.com/resource/software)

Visual Studio 2022: Link (https://visualstudio.microsoft.com/fr/downloads/)

Arduino IDE: Link (https://www.arduino.cc/en/software) ; Libraries: AccelStepper (1.64), SoftwareSerial (1.0)

Mustafa TOPBAS - Axel LEROY - Cédric DA CRUZ - Abigaïl BROCHARD - 4A GPSE

## C - CSR approach

For our project, we wanted to be as ecological as possible. Being a non-ecological project due

to critical raw materials, inevitable in electronic components, we want to follow an environmentally

friendly life cycle.

For the following items, our main objectives are in bold and our overshoot objectives are to be able to achieve everything

➔ Selection of materials with the least environmental impact
➔ Optimization of product’s lifespan
➔ Reduction in the quantity of materials
➔ Reduce the environmental impact of the use phase
➔ Optimization of the end of life of the system

We have already accounted for :

Selection of materials with the least environmental impact

- Rechargeable battery
- Divisible into several parts

Optimization of product’s lifespan

- Try to use sustainable materials from ethical sites

Optimization of the end of life of the system

- Facilitate recycling at end-of-life

List (not exhaustive) of raw materials present in our project:

- PLA (support)
- Polycarbonate (protection panel)
- Copper (wires and PCB)
- Silicon (semi-conductor)
- Polyepoxyde resin (PCB)
- Stainless steel (motor)

s


Mustafa TOPBAS - Axel LEROY - Cédric DA CRUZ - Abigaïl BROCHARD - 4A GPSE

## D - Distribution of work


Mustafa TOPBAS - Axel LEROY - Cédric DA CRUZ - Abigaïl BROCHARD - 4A GPSE

## E - Self-assessment of skills acquired/strengthened and CV

Mustafa TOPBAS - Axel LEROY - Cédric DA CRUZ - Abigaïl BROCHARD - 4A GPSE

## Self-assessment of skills acquired/strengthened – Mustafa

My role in this project is unique because I am responsible for project management in addition

to completing my personal tasks as a team member. Initially, I worked on the "Power supply and the

fan" part of the project while actively participating in all the collaborative work. I also worked with Axel

using Capella to write the use case and the functional diagram. Together with Axel, we built the

prototype of the propeller. Later, I will handle the design and manufacturing of the PCB, which will be

the core of the project — the blade. My role as project manager also required me to guide my

teammates when necessary. I led our group meetings to assign tasks according to each member's

preferences and ensured an equitable distribution of work as best as possible. Additionally, I propose

the topics for each PEA session and organize calls outside of PEA to coordinate everyone's availability.

I am also responsible for overseeing the general structure of the reports and presentation slides,

preparing the format, introduction, and conclusion so that each member can later add their personal

contributions. It is my responsibility to monitor project progress to avoid delays. I try to stay ahead

with my personal work on the documentation to set an example for the others to follow. I also created

the project Gantt chart, though I am not fully satisfied with it, as I feel it does not adequately reflect

each member’s involvement. I believe I can improve in this area.

My personal contribution to the project has allowed me to enhance my electronics skills,

particularly in working with inductive energy transmission, and I collaborated with Axel on the

prototype. I also learned to use Capella by applying what we studied with Mr. Drouin. This project

revisited project management concepts I began exploring last year, including use cases, functional

diagrams, etc. I volunteered to be project manager because I wanted to develop all the skills this role

entails, and I am satisfied with the practical experience I have gained so far.


Mustafa TOPBAS - Axel LEROY - Cédric DA CRUZ - Abigaïl BROCHARD - 4A GPSE


Mustafa TOPBAS - Axel LEROY - Cédric DA CRUZ - Abigaïl BROCHARD - 4A GPSE


Mustafa TOPBAS - Axel LEROY - Cédric DA CRUZ - Abigaïl BROCHARD - 4A GPSE

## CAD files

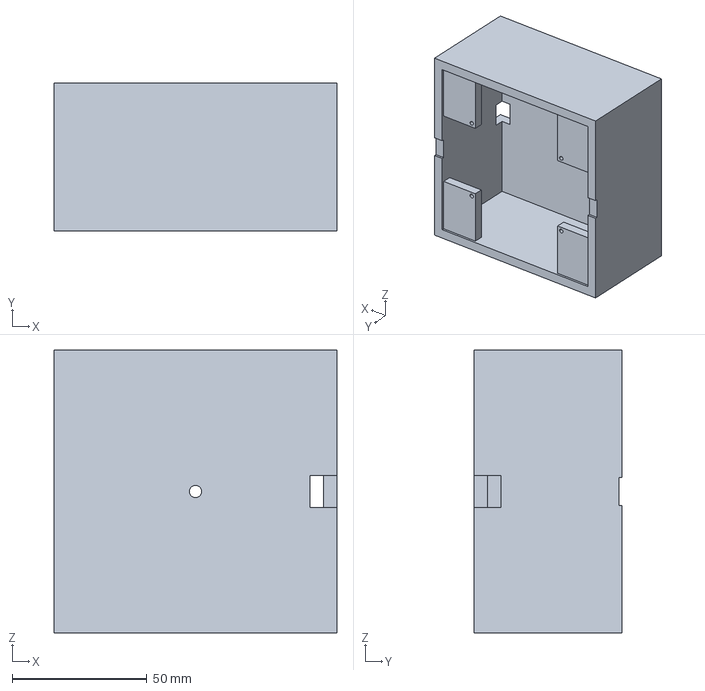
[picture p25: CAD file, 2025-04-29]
Manifecture/PLA PCB case/boitier_pcb.stp
105.0 x 55.0 x 105.0 mm

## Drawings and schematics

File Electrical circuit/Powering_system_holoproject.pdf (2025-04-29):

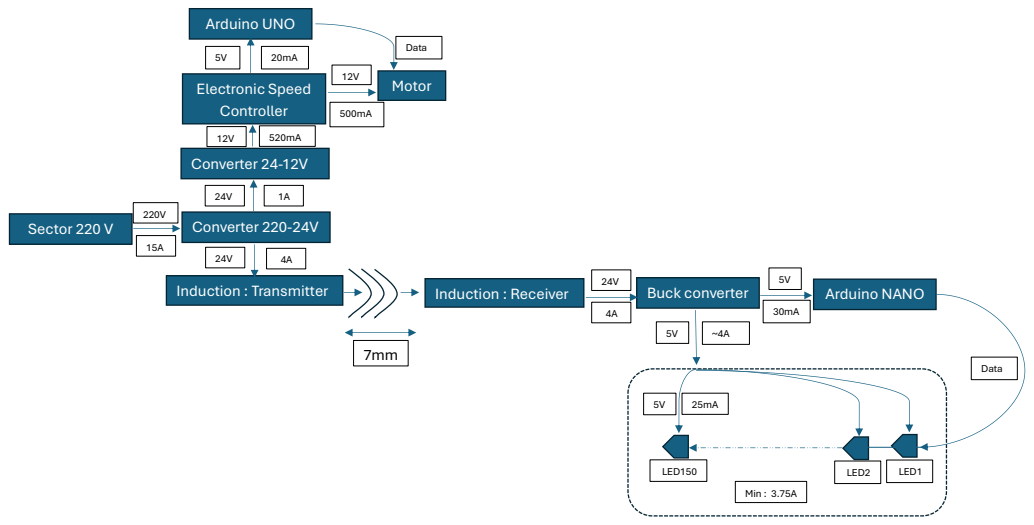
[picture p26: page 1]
Sector 220 V; Converter 220-24V; Electronic Speed Controller; Motor; Arduino UNO; Converter 24-12V; Induction : Transmitter; Induction : Receiver; Buck converter; Arduino NANO; LED150; LED2; LED1; Data; Min : 3.75A

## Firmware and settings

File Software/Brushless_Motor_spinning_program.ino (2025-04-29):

#include <Servo.h>

int val = 1063;
Servo esc;  
const int escPin = 6;  

void setup() {

  //Phase d'initialisation
    Serial.begin(9600);
    esc.attach(escPin);
    esc.writeMicroseconds(2000);     
    delay(3000);
    esc.writeMicroseconds(1000); 
    delay(3000);
    
    Serial.println("Calibration/Initialisation terminée.");
    delay(3000);
}

void loop() 
{

  /*
    //Code test vitesse + consommation
    for(int i=0;i<22;i++)
    {
      esc.writeMicroseconds(val);
      delay(10000);
      val=val+50;
    }
   */
      esc.writeMicroseconds(val);
      delay(10000);
}

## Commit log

2025-04-29 motor spinning program
2025-04-29 Create PLA PCB CASE folder
2025-04-29 3D print files for the PLA PCB case
    [boitier_pcb.stp]
2025-04-29 Create electrical circuit
2025-04-29 elctrical circuit files
2025-04-30 C# code for the fan (Test+Full App)
